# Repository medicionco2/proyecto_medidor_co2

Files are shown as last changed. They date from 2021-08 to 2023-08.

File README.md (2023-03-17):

# Medidor CO2 para prevención de contagios por aerosoles en ambientes interiores

> Este proyecto está en plena evolución. Este texto, los programas, y demás materiales se están actualizando frecuentemente.

Al respirar, absorbemos oxígeno del aire y al exhalar expulsamos dióxido de carbono (CO2). En ambientes interiores, con el correr de los minutos, si no se ventila, la respiración de las personas allí presentes hace que suba la concentración de CO2. Dicho en números, al aire libre la concentración de CO2 es de 400 ppm (partes por millón), mientras que en la exhalación de las personas, hay 40 mil ppm. Se ha demostrado que hay correlación entre esa concentración y el riesgo de contagio de enfermedades respiratorias. Por supuesto, ese riesgo varía según la proporción de personas infectadas en la región. Se estima que si la concentración de CO2 alcanza las 800 ppm, eso quiere decir que el 1% del aire que respiramos ya fue respirado por otra persona. Cuando se supera ese valor, la permanencia en ese espacio comienza a ser riesgosa. Recordemos que hay una antigua prescripción médica sobre ventilar para prevenir el contagio de enfermedades respiratorias. Durante la pandemia de COVID-19, esa recomendación se transformó en la principal para minimizar el riesgo de contagio. En resumen, es importante medir la concentración de CO2 para saber si un ambiente interior está suficientemente ventilado dada una cierta cantidad de gente y el tiempo transcurrido realizando una actividad. 

Contagio por aerosoles

> Tiene que quedar claro que si en un ambiente se mide más de 2000 ppm de CO2, hay que tomar medidas urgentemente porque realizar actividades allí es peligroso.

Se propone el diseño de un dispositivo medidor de CO2, de uso orientativo, para espacios interiores, como medida de prevención de enfermedades infecciosas que se contagian mediante aerosoles (por ejemplo, COVID-19). 

El objetivo es que el dispositivo propuesto sea de uso sencillo, lo más económico posible, de diseño libre, y con el potencial para desarrollar toda la funcionalidad de los dispositivos comerciales más avanzados. El dispositivo solamente tiene cuatro componentes. Además del sensor y la computadora, hay un LED RGB para indicar, mediante colores, el nivel de concentración de CO2 en el ambiente interior donde se use. El cuarto componente, es simplemente un pulsador. 

El diseño cuenta con una computadora de placa reducida, también llamado de placa única, de placa simple (SBC), o sistema en un chip (SoC), de bajo costo. En este caso, el sistema propuesto es de la familia ESP32 con tecnología Bluetooth y WiFi integrada. Por eso último, el instrumento no va a necesitar una pantalla, en su lugar, una app para Android o una aplicación web, van a mostrar los valores de CO2 actuales, las series de tiempo, y otros análisis para estudio y toma de decisiones (por ejemplo, ventilar más, reducir el aforo, etc.).

La situación sanitaria evidencia la necesidad de usar este tipo de dispositivos, no solo en esta coyuntura, sino post-pandemia, como elemento que apunta a asegurar un nivel de calidad de aire desde el punto de vista sanitario. En otras palabras, sería un elemento más de seguridad e higiene en espacios donde se realicen diferentes tipos de actividades humanas, incluida la educación en todos sus niveles.

### ¿Qué son los aerosoles?

Cuando hablamos, gritamos, cantamos, tosemos, estornudamos o simplemente respiramos, exhalamos partículas grandes y también partículas pequeñas ("aerosoles") que están formadas por saliva o líquido proveniente de la tráquea, los pulmones, etc. Lo mismo que las partículas grandes, estos aerosoles pueden "portar" virus, que pueden infectar cuando se inhalan.

Aerosoles

## Lista de materiales

Cualquier persona o grupo con entusiasmo, con un poco de conocimiento de electrónica e informática, y muy pocas herramientas puede construír este medidor. 

Se necesitan cuatro componentes más los cables de conexión y el gabinete.
1. ESP32: Hay diversos modelos y versiones del SoC ESP32.
2. Sensor MH-Z19b (o c, que es más actual): asegurarse que es original (Winsen)

Sensor MH-Z19b

Sensor MH-Z19c

3. Pulsador
4. LED RGB más 3 resistencias 220 ohm. Por simplicidad, se recomienda que sea en un solo módulo, como en la siguiente figura:

Modulo LED RGB

En esta aplicación, el significado de los colores es el siguiente:
- Verde significa baja concentración de CO2, bajo riesgo de contagio por aerosoles.
- Amarillo es acercándose a riesgo alto.
- Rojo es riesgo alto, debe ventilarse el ambiente.
- Violeta es riesgo alto, debería evacuarse momentáneamente el ambiente.

El LED en azul significa que el sensor se está calentando o que el aparato está en modo de calibración.

Desarrollamos una caja a medida imprimible en 3D. Se agradece a [Franco Perez](https://github.com/FrancoGabrielPerez) por su colaboración en el desarrollo del diseño 3D de la caja. También se agrade por su colaboración inicial a [Tomas Aranda](https://github.com/jarandat).

https://user-images.githubusercontent.com/53094209/226057489-6c33f7e1-ac5b-46c4-9dbb-f1a19d471beb.mp4

Mientras tanto, o alternativamente, a caja puede ser una caja de paso de las que se usan en electricidad, de las más pequeñas. Es importante que hagas dos ranuras por donde el sensor vea el exterior de la caja. Las ranuras son para las dos "ventanitas" blancas que se ven en la figura del sensor.

### Sobre el sensor

El sensor seleccionado, MH-Z19b, se basa en tecnología de detección de gas por absorción de luz infrarroja. Más precisamente, la tecnología que usa se conoce como NDIR (del inglés nondispersive infrared).

No todos los sensores MH-Z19b que se pueden adquirir son iguales, su diseño y su firmware han ido evolucionando. La librería que usamos permite acceder al "Firmware Version", por ejemplo los que tenemos son versión 5.02. Hay que notar que el fabricante (Winsen, China) no ha documentado todos los cambios y algunas veces hay que recurrir a ingeniería inversa para descubrir algunas de sus características. Aún así, se considera que es un sensor económico con una relación precio/prestaciones muy buena.

Advertencia: El sensor es sensible a la electricidad estática. Tratar al sensor con ciudado, es un componente delicado.

## Conexión de componentes

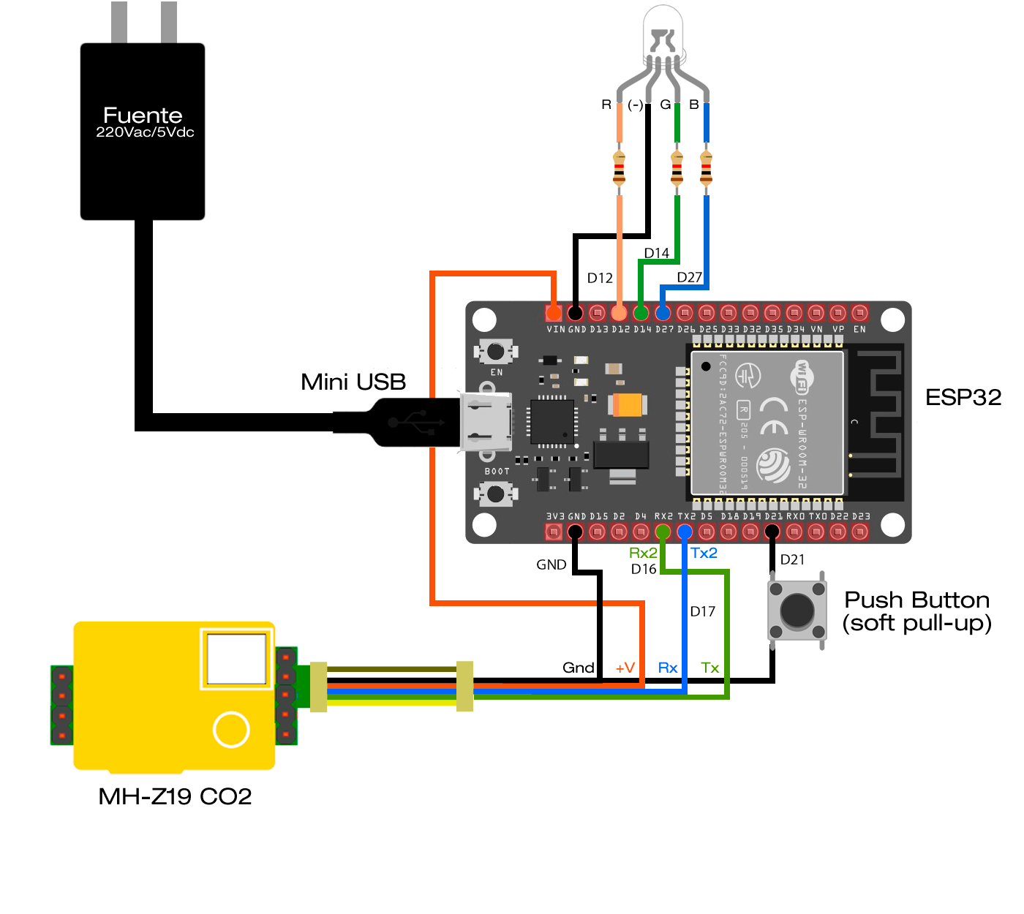
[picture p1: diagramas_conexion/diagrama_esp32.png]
Diagrama de conexiones


La alimentación del dispositivo se hace mediante un cargador USB estándar.

El sensor puede venir con un cable armado con una ficha que no es compatible con los conectores del ESP32. Por eso, una alternativa es cortar el cable y empalmar cables dupont.

Para más ayuda, [este video](https://www.youtube.com/watch?v=vmDCqNXVZKQ) muestra en detalle cómo se conecta el sensor MH-Z19b al ESP32. 

En resumen, conectar el sensor requiere de 4 cables: 
- Alimentación (5V): cable rojo del sensor 
- tierra (GND): cable negro
- y los dos cables de la conexión serie: cable azul a pin Tx2 (o puede aparecer impreso con número 17) y cable verde a Rx2 (o 16). 

## Programación

1. Instalar IDE Arduino en una PC. 
2. Instalar soporte para ESP32.
Las instrucciones para estos dos primeros pasos se pueden ver en [este enlace](https://randomnerdtutorials.com/installing-the-esp32-board-in-arduino-ide-windows-instructions/) 
	
3. Instalar librería para el sensor MH-Z19b.
	https://downloads.arduino.cc/libraries/github.com/WifWaf/MH_Z19-1.5.3.zip
	
   También se puede usar el gestor de librerías. Para ello, se puede ir, en el Arduino IDE, al menu “Herramientas”, allí “Administrar Librerías…”. Aparece una ventana donde se puede buscar “MH-Z19”, que es nuestro sensor, y vamos a instalar la librería seleccionada en la figura, es decir, la de “Jonathan Dempsey”.
   
4. Copiar y compilar el código fuente seleccionado usando Arduino IDE.

5. Descargar el código ejecutable en el ESP32 de manera que quede programado con la aplicación seleccionada.

## Funcionamiento

Una vez conectado el cable USB, el dispositivo se pone en funcionamiento. No hay botón de encendido. El sensor tarda tres minutos para iniciar sus medidas, eso se indica con el LED encendido en color azul. Pasado ese tiempo, el LED indica la concentración de CO2 mediante colores: verde (poca concentracón de CO2, más seguro), amarillo, rojo y violeta (muy alta concentración de CO2, menos seguro). A su vez, se envían las medidas de CO2 y temperatura por WiFi o Bluetooth, según cuál programa se haya cargado en el dispositivo. 

Si se seleccionó la versión Bluetooth, se pueden ver las medidas en un teléfono inteligente. Una posibilidad es usar la app "Serial Bluetooth Terminal" que se pude descargar en el teléfono desde https://play.google.com. En ese caso vas a ver los datos que vienen del medidor de esta manera:

Captura Serial Bluetooth Terminal

### Cómo debería usarse el medidor

En un espacio interior con cierta ventilación fija, por ejemplo con las ventanas parcialmente abiertas, se debería llegar a una situación en la cual el CO2 que exhalan las personas sea igual a la cantidad de CO2 que sale por las ventanas, de modo que el nivel de CO2 en la habitación se mantenga aproximadamente constante. El objetivo debe ser que ese valor estable de CO2 no supere los 700 a 800 ppm.

Si se observan valores estables de CO2 demasiado altos, superiores a 800 ppm, se deben abrir las ventanas un poco más. Si eso no es posible porque la temperatura del exterior es demasiado baja, se debe reducir el número de personas que realiza la actividad o reducir la duración de la actividad. Si la temperatura exterior fuera confortable, se recomienda abrir las ventanas completamente.

El viento hace que mejore la ventilación. En días ventosos, es probable que se logren los valores deseados de CO2 con menor apertura de las ventanas.

> Ventilar los pasillos en las escuelas (y otros edificios con varios espacios comunicados) es muy importante, ya que de lo contrario transfieren el aire exhalado entre las aulas.

imagen

### En qué lugar del espacio interior colocar el medidor

Lo ideal es colocarlo a la altura de la respiración de las personas (1,5 m) del lado opuesto a las ventanas. No colocarlo muy cerca de las personas.

Se puede experimentar moviendo el medidor de CO2 a diferentes lugares de la habitación. Si se detecta una zona menos ventilada, allí debe colocarse el medidor para que indique el caso más desfaborable.

### Calibración

Al aire libre, la concentración de CO2 es cercana a las 400 ppm. Si ves que en un ambiente muy bien ventilado, el medidor está dando una medida alejada de esas 400 ppm, seguramente haga falta calibrarlo.

Si bien existen diferentes [técnicas de calibración](https://www.co2meter.com/blogs/news/7512282-co2-sensor-calibration-what-you-need-to-know), en este caso vamos a poner el dispositivo al aire libre. Hay que notar que el proceso se ve afectado por el viento y las temperaturas extremas. Alternativamente, el medidor se puede calibrar en un espacio MUY bien ventilado. Para comenzar el proceso de calibración, oprimir el pulsador por al menos un segundo y esperar al menos 20 minutos. En ese estado, el LED está encendido en color azul con intensidades variables que se repiten cíclicamente. 

Alternativamente, existe un modo de calibración que se llama [Automatic Background Calibration](https://www.co2meter.com/blogs/news/9290675-automatic-background-calibration-abc-in-senseair-co2-sensors-explained) (ABC). En este modo el sensor mide durante 24 horas, se queda con el mínimo y usa ese mínimo para ajustar de manera que ese valor mínimo pase a ser 400 ppm. Si el ambiente interior se usa de manera que durante una parte del día se ventile lo suficiente, esta estrategia funcionaría de manera automática, sin intervención de usuarios.

## Propuesta

Con motivaciones parecidas, en Internet existen varios proyectos como éste. En este caso, el concepto que nos guía es el de *IoT, Internet de las Cosas*, donde el hardware es mínimo, con conexión a Internet, y donde el valor está en el software, hasta llegar a usar una plataforma IoT. Esas plataformas (existen más de 600 diferentes) proveen servicios como seguridad, actualización remota del software, visualización de los datos, gestión de eventos, gestión de los propios dispositivos en el caso que se usen varios, o muchos, y por qué no miles.

Otra diferencia es que este proyecto se centra en *un solo tipo de sensor y un solo tipo de "computadora de placa simple"*. Existen varias alternativas para ambos, pero para quien comienza, creemos que es más sencillo tener una sola plataforma. Como decíamos, el concepto que nos guía es que el valor va a estar en el software. En cuanto al software, sí proponemos diferentes versiones para Wifi, Bluetooth, con funcionalidad básica, y esperemos que pronto, funcionalidad más avanzada.

> Y lo más importante de todo: Generar conciencia sobre la seguridad e higiene del aire que respiramos en ambientes interiores. Higiene

Te invitamos a sumarte a este proyecto, a construír tu propio medidor, compartir resultados, y a extender el hardware pero sobre todo, el software. Para consultas, por favor, escribir a etodorov@exa.unicen.edu.ar.

## ¿Estos medidores compiten con los medidores comerciales?

En este proyecto, de ninguna manera competimos con los medidores comerciales. De hecho, te invitamos a visitar [páginas de fabricantes de medidores en Argentina](https://www.argentina.gob.ar/ciencia/unidad-coronavirus/ventilar/produccion-local-medidores) para más información. Los medidores de este proyecto pueden complementar, llegando a los sectores de menos recursos donde las soluciones comenciales son inaccesibles, ayudando al objetivo fundamental de la prevención y la toma de consciencia sobre la vía de contagio por aerosoles. 

## Más Información

- La concentración de CO2, además de poder medirse, se puede calcular en base al tamaño de la habitación, la cantidad de personas presentes y la ventilación. Esta última se mide en "cambios de aire por hora". https://forhealth.org/tools/co2-calculator/

- Este artículo del diario "El País", de octubre de 2020, es insuperable desde el punto de vista comunicacional. https://elpais.com/ciencia/2020-10-24/un-salon-un-bar-y-una-clase-asi-contagia-el-coronavirus-en-el-aire.html

- [Importancia de la ventilación para la prevención de la COVID-19](https://youtu.be/fpMb1TzraGw).  Canal del Ministerio de Ciencia, Tecnología e Innovación, 26 marzo de 2021.   

- [Recomendaciones para la prevención de transmisión de COVID-19 por aerosoles](https://www.argentina.gob.ar/sites/default/files/covid-19-prevencion-de-transmision-por-aerosoles-2021.pdf) del Ministerio de Ciencia, Tecnología e Innovación y Ministerio de Salud.

- Campaña [Ventilar](https://www.argentina.gob.ar/ciencia/unidad-coronavirus/ventilar) para la prevención de la transmisión del COVID-19 por aerosoles, del Ministerio de Ciencia, Tecnología e Innovación, Argentina.

- [Guía de evaluación de la frecuencia de ventilación](https://schools.forhealth.org/ventilation-guide/). Programa "Healthy Buildings" de la Escuela de Salud Pública T.H. Chan, Universidad de Harvard. 

- [Guía del Consejo Superior de Investigaciones Científicas](https://www.csic.es/en/node/1259002) (España) sobre cómo se deben ventilar para reducir el riesgo de contagio por Covid-19. 

- [Estimación de riesgo de contagio simplificada](https://www.nationalgeographic.com/science/article/how-to-measure-risk-airborne-coronavirus-your-office-classroom-bus-ride-cvd) de National Geographic.

- Natalia Rubinstein, Ciclo Ciencia para ventilar: [Yo ventilo, ella ventila, vos ventilás. ¿Pero lo hacemos bien?](https://youtu.be/4q3odycwvYs).

- Sandra Cordo, Ciclo Ciencia para ventilar: [Transmisión de Covid-19 por aire. Principales medidas de prevención](https://youtu.be/4AUWS4Dpn0A).

- Alejandro Nadra, Juan Fernández Zaragoza, Ciclo Ciencia para ventilar: [¿Qué son las tecnologías libres y qué aportan en el contexto de pandemia?](https://youtu.be/301sSYFhCg8).

---

- [Jornada sobre Ventilación para bares y restaurantes](https://youtu.be/Q7DBwQ0G1Hc) en contexto de COVID 19, donde se presentaron [líneas de financiamiento](https://www.argentina.gob.ar/servicio/obtener-un-credito-para-mi-restaurante-o-bar) de la Secretaría de la Pequeña y Mediana Empresa y los Emprendedores de Argentina, hasta 31 de octubre de 2021.

---

- Proyectos afines y material técnico

	- Proyecto del [Dr. Jorge Aliaga]((http://www.jorgealiaga.com.ar/?page_id=2864)) de [Medición de CO2](https://github.com/jlaliaga/Medidor-de-CO2)  

	- Proyecto [Aireamos](https://www.aireamos.org), como coalición de grupos liderados por científicos en el área.

		- [Comparativas y guías](https://www.aireamos.org/medidores/) sobre medidores comerciales de CO2.
      
	- [Proyecto LibreCO2](https://github.com/danielbernalb/LibreCO2) de [Daniel Bernal](https://aireciudadano.com/guia-de-construccion-medidor-libreco2/) donde se propone el uso de tarjetas Arduino.
      
	- Un [medidor de CO2](https://emariete.com/medidor-casero-co2/) de eMariete.

		- [Ciudado con los sensores *fake*](https://youtu.be/dWYMuFZt8kk).

	- [Proyecto CODOS](https://github.com/miguelangelcasanova/codos).

	- [Comparativa de sensores](https://soloelectronicos.com/2020/11/01/monitor-de-co2-con-sensor-mh-z19/): Recomiendan el MH-Z19, lo mismo que Jorge Aliaga. Aunque la medida de temperatura que provee el propio sensor no es precisa, al tener esa medida junto con CO2, se puede controlar la habitabilidad de un espacio con un criterio CO2 y temperatura combinado.

	- ¿Cómo funcionan los sensores de tecnología NDIR? Explicación sencilla en [co2meter.com](https://www.co2meter.com/blogs/news/6010192-how-does-an-ndir-co2-sensor-work)
      
 - Artículos científicos

	- Zhe Peng and Jose L. Jimenez, "Exhaled CO2 as a COVID-19 Infection Risk Proxy for Different Indoor Environments and Activities", Environmental Science & Technology Letters, 2021, 8 (5), 392-397. https://pubs.acs.org/doi/10.1021/acs.estlett.1c00183

	- Greenhalgh T, Jimenez JL, Prather KA, Tufekci Z, Fisman D, Schooley R. "Ten scientific reasons in support of airborne transmission of SARS-CoV-2". Lancet. 2021; 397: 1603-1605. https://www.thelancet.com/journals/lancet/article/PIIS0140-6736(21)00869-2/fulltext

	- Liu, Y, Misztal, PK, Xiong, J, et al., "Detailed investigation of ventilation rates and airflow patterns in a northern California residence", Indoor Air, 2018; 28: 572–584. https://onlinelibrary.wiley.com/doi/10.1111/ina.12462

	- Johansson MA, Quandelacy TM, Kada S, et al. "SARS-CoV-2 transmission from people without COVID-19 symptoms". JAMA Netw Open 2021; 4: e2035057.

	- Lidia Morawska, Donald K Milton, "It Is Time to Address Airborne Transmission of Coronavirus Disease 2019 (COVID-19)", Clinical Infectious Diseases, Volume 71, Issue 9, 1 November 2020, Pages 2311–2313. https://academic.oup.com/cid/article/71/9/2311/5867798
		- Este paper fue suscrito por más de 200 científicos.

	- Hou YJ, et al. SARS-CoV-2 Reverse Genetics Reveals a Variable Infection Gradient in the Respiratory Tract. Cell. 2020 Jul 23;182(2):429-446. https://www.ncbi.nlm.nih.gov/pmc/articles/PMC7250779/pdf/main.pdf

	- Miller, SL, Nazaroff, WW, Jimenez, JL, et al. Transmission of SARS-CoV-2 by inhalation of respiratory aerosol in the Skagit Valley Chorale superspreading event. Indoor Air. 2021; 31: 314– 323. https://onlinelibrary.wiley.com/doi/epdf/10.1111/ina.12751

	- Shrey Trivedi, Savvas Gkantonas, Léo C. C. Mesquita, Salvatore Iavarone, Pedro M. de Oliveira, and Epaminondas Mastorakos, "Estimates of the stochasticity of droplet dispersion by a cough", Physics of Fluids 33, 115130 (2021) https://doi.org/10.1063/5.0070528 
		- Este paper fue citado en un [artículo periodístico](https://www.pagina12.com.ar/385125-coronavirus-advierten-que-con-el-distanciamiento-social-no-a) donde los investigadores concluyeron que el distanciamiento de dos metros no debe considerarse una medida de seguridad por sí sola, sino que para ser efectiva tiene que estar acompañada por la utilización de barbijos, la ventilación de espacios y la vacunación. “Todos estamos desesperados por ver la parte posterior de esta pandemia, pero recomendamos encarecidamente que las personas sigan usando máscaras", al menos en "espacios interiores", dijo Epaminondas Mastorakos, experto en mecánica de fluidos de la Universidad de Cambridge. "No hay ninguna buena razón para exponerse a este riesgo mientras el virus esté con nosotros”, añadió.

- El proyecto en los medios

	- En el canal de YouTube de El Taller De TD imagen [explicaron el proyecto](https://youtu.be/7OHqT15nE9wimagen
), 11 OCT 2021. ¡Gracias!

	- Exactas Dialoga, 5 OCT 2021. [Medidor sencillo de dióxido de carbono.](https://www.mixcloud.com/Exactasdialoga/exactas-dialoga-e5-medidor-sencillo-de-di%C3%B3xido-de-carbono/)

	- Diario "ABC Hoy" de Tandil, 30 SEP 2021. [Alumnos de 5° Año del Colegio Nuestra Tierra diseñaron un detector de Dióxido de Carbono.](http://www.abchoy.com.ar/leernota.php?id=178465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)

	- Diario "La Voz de Tandil", 29 SEP 2021. [Estudiantes del Colegio Nuestra Tierra construyeron un medidor de dióxido de carbono.](https://www.lavozdetandil.com.ar/2021/09/29/estudiantes-del-colegio-nuestra-tierra-construyeron-un-medidor-de-dioxido-de-carbono)

	- Portal "Enfoque de Negocios", 16 JUL 2021. [Se fabricarán medidores de Dióxido de Carbono en Tandil.](https://www.enfoquedenegocios.com.ar/medidores-de-dioxido-de-carbono/)

	- [Presentación del proyecto](https://youtu.be/HmPg_Kn5Qhk) en el Encuentro IoT MdP/Tandil 2021 en el marco del proyecto [NEON](https://www.project-neon.eu/) de la Unión Europea, 13 JUL 2021. 

	- Diario "El Eco" de Tandil, 3 JUL 2021. [Investigadores de Exactas inventaron un medidor de dióxido de carbono con un diseño económico y simple.](https://www.eleco.com.ar/la-ciudad/investigadores-de-exactas-inventaron-un-medidor-de-dioxido-de-carbono-con-un-diseno-economico-y-simple)

	- Boletín de la Facultad de Ciencias Exactas - Número 274 - Reunión con la Dirección Nacional de Desarrollo Tecnológico e Innovación del MinCYT, 28 JUN 2021. (En redes sociales de la Facultad de Ciencias Exactas, UNICEN)

	- Diario "ABC Hoy" de Tandil, 23 JUN 2021. [Medidor de dióxido de carbono para concientizar sobre ventilación para prevención del COVID-19.](http://www.abchoy.com.ar/leernota.php?id=175998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)

	- Diario "El Eco" de Tandil, 23 JUN 2021. https://www.eleco.com.ar/la-ciudad/crean-un-medidor-de-dioxido-de-carbono-que-busca-concientizar-la-importancia-de-la-ventilacion-de-los-ambientes

	- Boletín de la Facultad de Ciencias Exactas - Número 273 - Crean un medidor de Dióxido de Carbono que busca concientizar la importancia de la ventilación de los ambientes para evitar la propagación del COVID-19, 22 JUN 2021. (En redes sociales de la Facultad de Ciencias Exactas, UNICEN)

¿Se puede usar esta información en otras publicaciones?

Si, se puede utilizar. De hecho, nosotros consultamos numerosas fuentes que tratamos de documentar en esta sección. No es necesario que te pongas en contacto con nosotros para pedirnos permiso. Sólo te pedimos que indiques el enlace a esta página como fuente de la información. Si es posible, incluir la fecha en la que viste la información. Si necesitas una lista de autores, sólo tienes que enumerar a las personas que contribuyen en este proyecto en la fecha que accediste.

Con respecto al código fuente, recuerda que tiene licencia GPL, lo cual permite usar, estudiar, compartir (copiar) y modificar el software, siempre que preserves estas libertades.

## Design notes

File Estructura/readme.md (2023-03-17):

La estructura esta diseñada en Fusion360, se incluye un .f3z que contiene el ensamblaje completo de la estructura. Ademas se incluyen tres archivos .stl correspondientes a las diferentes partes del diseño.
Esta diseñado para ser impreso sin soportes.

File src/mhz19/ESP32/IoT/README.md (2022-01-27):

## thingspeak

Thingspeak (https://thingspeak.com) es un proyecto open source (https://github.com/iobridge/thingspeak) creado en 2010. Actualmente, está integrado con el software MATLAB de MathWorks al punto que hay que crear una cuenta en MathWorks para usar la plataforma en thingspeak.com. 

Para usar esta alternativa hay que: 

1. Comenzar siguiendo los pasos que se explican en https://la.mathworks.com/help/thingspeak/collect-data-in-a-new-channel.html.

2. Crear un channel y configurarlo para recibir dos "Fields", uno va a contener la lectura de CO2 y otro la temperatura del sensor.

Channel Settings

3. Si ya seguiste los [pasos](https://github.com/medicionco2/proyecto_medidor_co2#programaci%C3%B3n) de las versiones básicas, ya tenías cargada la librería del sensor. Ahora, tenés que cargar la librería thinkspeak que está disponible en el repositorio de Arduino.

Lib thikgspeak

4. Editar el archivo secrets.h, que debe incluirse en el IDE de Arduino, indicando tu "Channel Id" y tu "Write API Key" en thingspeak. Los API Key son 16 números y letras, tachados por seguridad en la figura.

API Key

5. Configurar el ESP32 con ese programa. 

El medidor en funcionamiento va a comenzar a enviar datos a la plataforma thingspeak. Vas a poder configurar visualizaciones de manera más o menos intuitiva de manera que veas algo así:

thingspeak Visualization

Licencia seleccionada: FREE (For small non-commercial projects)

  - Scalable for larger projects:   No. Annual usage is capped.
  - Number of messages:             3 million/year (~8200/day)
  - Message update interval limit:  Every 15 seconds 
  - Number of channels:             4
  - MATLAB Compute Timeout:         20 seconds
  - Number of simultaneous MQTT subscriptions: Limited to 3
  - Private channel sharing:        Limited to 3 shares
  - Technical Support:            	Community Support 

Para tener más nivel de servicio (conectar más sensores, compartir con más gente, mejores tasas de datos, etc.), hay que adquirir alguna licencia de pago: Standard, Academic, Student, o Home.

### ¿Cómo crear un dashboard sencillo para ver la telemetría de todos los sensores en una página web?

A continuación te explicamos cómo hacerlo.

#### Embebiendo Código de Cuadros de Medición y Visualización de Thingspeak

Si queremos agregar un cuadro de visualización de una medición dentro de una página web, debemos embeber una porción de código html. Para realizarlo, dentro de thingspeak.com con nuestra cuenta y nuestro canal que queremos mostrar, debemos seleccionar el cuadro del campo ("Field") que queremos mostrar y debemos seleccionar el icono que se muestra a continuación: 

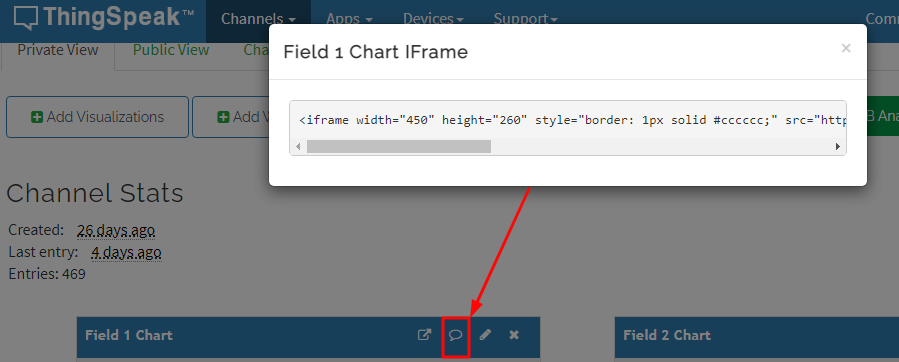
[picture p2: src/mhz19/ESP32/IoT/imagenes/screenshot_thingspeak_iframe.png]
thingspeak Código Cuadros de Medición y Visualización embebido


Una vez seleccionado el icono tendremos acceso a copiar el código a embeber, se trata de una etiqueta iframe que puede agregarse en cualquier sitio web. Si aún no tenemos un sitio web, podemos pegar ese código en un archivo y pasar al paso de crear un sitio web.

#### Creando un sitio web en Google Sites

Si disponemos de una cuenta de gmail, podemos desarrollar un sitio web que estará alojado en Google, accesible por cualquier persona.
Una vez iniciada nuestra cuenta de gmail, se puede acceder a https://sites.google.com/ para comenzar a costruir un sitio web.

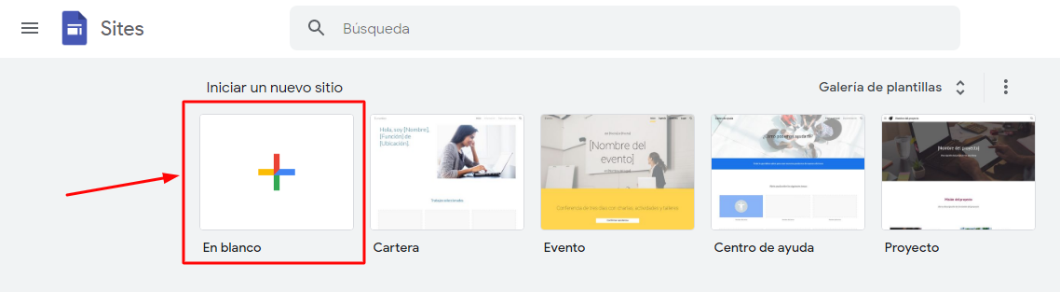
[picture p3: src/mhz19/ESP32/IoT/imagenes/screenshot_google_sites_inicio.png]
Inicio Google Sites


Una vez que se ingresa al inicio de la construcción de nuestro sitio en Google, se puede agregar un título a nuestra página, bloques de estructra, estilos, etc. Aquí lo importante es que para mostrar nuestras mediciones debemos agregar un bloque que permita pegar nuestro código de thingspeak. Ese bloque que permite introducir códgo html, se puede agregar como indica la figura, cliqueando en "Incorporar <>" y luego dentro del cuador de diálogo seleccionando "Incorporar código" nos permite en el casillero de texto pegar nuestro código generado desde thingspeak para nuestro cuadro de medición y visualización.

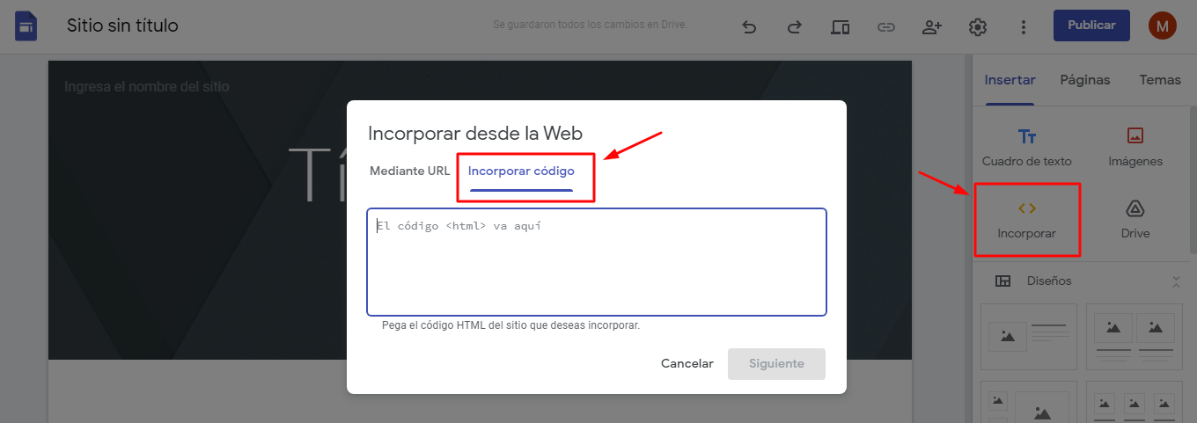
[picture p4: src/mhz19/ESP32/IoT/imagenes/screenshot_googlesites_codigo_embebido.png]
Embebiendo Cuadros de Medición y Visualización de Thingspeak en Google Sites


Luego para finalizar podemos hacer más ajustes de alineación y estilo de nuestra página y publicarla. Si en esa misma página queremos mostrar otro gráfico,y esa es la idea de un dashboard, o cuadro de control, repetimos los pasos anteriores.

## Autodescubrimiento de la red WiFi

En versiones simples del firmware, por ejemplo para hacer un solo medidor, el nombre de la red WiFi (conocido como SSID) y la contraseña, se proporcionan en el programa, en nuestro caso, en el archivo secrets.h. Si se cambia el router, o se lleva el medidor a otra red, hay que volver a editar el archivo secrets.h y reprogramar el medidor. Si bien esa forma de conectarse a la red WiFi es sencilla, por un lado es incómodo para los usuarios tener que reprogramar los medidores, y por otro lado complica el despliegue en instituciones que necesiten de un número relativamente grande de medidores. Una solución es agregar una funcionalidad que se llama autodescubrimiento de la red WiFi (o WiFi provisioning).

Esta técnica va a permitir distribuír medidores ya programados, que no deberán reprogramarse, de manera que sean más sencillos de usar para los usuarios finales. Sin embargo, para quienes quieran estudiar el programa, se van a encontrar con un código más complejo que en el caso simple de arriba.

WiFi provisioning es un proceso que va a servir para cargar en el medidor- sin tener que programar- el SSID, password, e información para enviar los datos a la plataforma IoT, en este caso Thingspeak. Esta funcionalidad puede ser muy útil en dispositivos IoT como nuestro medidor. El medidor va a poder estar en uno de dos modos: con la configuración cargada o sin la configuración cargada. Si la configuración no está cargada, el medidor se va a comportar como un Access Point y lo vamos a ver entre las redes WiFi disponibles, caso contrario el medidor se conecta a la red que tiene configurada y opera normalmente midiendo y enviando datos a la plataforma IoT.

Para usar el medidor con esta funcionalidad hay que hacer los tres primeros pasos (1-3) de las instrucciones de aquí arriba, luego:

4. Configurar el ESP32 con el programa correspondiente (Thingspeak_WiFi_provisioning.ino). Se le puede entregar el medidor a un usuario final con estos 4 pasos hechos, así él o ella, solamente va a tener que realizar el quinto paso sin tener que lidiar con tecnología. 

5. El medidor en funcionamiento va a enviar datos a la plataforma thingspeak como antes. Pero para que ello ocurra, primero lo vas a tener que configurar del siguiente modo:

  - Durante el primer arranque del dispositivo, el medidor se configura como un punto de acceso (AP - Access Point) y crea una red abierta Wifi sin contraseña con el nombre "redmedidor". Entonces, para establecer la conexion con el punto de acceso, en el dispostivo desde el que se desee conectar al medidor (teléfono, PC, etc.) se debe seleccionar esa red con el nombre "redmedidor". 

Conexión al medidor como Access Point

  - Esta red abierta WiFI permite al usuario conectarse al medidor a través de un navegador. Para ello, debe ingresarse la dirección http://192.168.4.1 en el navegador para acceder a la página web de configuración.

Configurando el medidor

  - Para dar una cierta seguridad, hay que ingresar usuario y contraseña para poder acceder al medidor. Si no los cambias en el programa, son: "esp32", "4321".

Ingreso a la configuración del medidor

  - Una vez seleccionado el nombre de red, contraseña, y demás información, el medidor se reinicia e intenta conectarse a la red asignada.

  - Si se establece la conexion el proceso de provisioning se ejecutó exitosamente.

  - En caso de falla o si se quiere modificar la red a la cual se conecta el medidor, se debe pulsar el botón por más de tres segundos para que el dispositivo pase nuevamente al modo de punto de acceso. 

## Actualización OTA del firmware

Tener un dispositivo como este medidor de CO2 progeamado y funcionando, no significa que esté libre de errores de programación o que nunca vaya a nececitar mejoras. Al contrario, mientras el proyecto esté activo, periódicamente se va a necesitar actualizar el código del ESP32, el firmware. Esto se puede hacer de diferentes maneras, la más sencilla es compilar el nuevo código y programar el ESP32 mediante el cable USB desde la PC. Es lo que se hace cuando se trabaja con prototipos, para hacer pruebas en casa, pero para un usuario esto puede ser demasiado tecnológico, no muy amigable. Más allá de eso, si tenemos una cantidad de medidores desplegados en un edificio, actualizar el firmware de esa manera también es impráctico. Aquí viene entonces la segunda manera: aprovechar la conectividad WiFi para actualizar el firmware remotamente, "over the air" (OTA). En este caso, quien administre los sensores y la plataforma IoT, va a subir la actualización a un servidor, posteriormente el ESP32 va a descargarla en su memoria y va a reiniciarse automáticamente. A partir de ese momento todos los medidores de ese edificio van a estar actualizados sin intervención de los usuarios. Es un mecanismo muy usado, de hecho es lo que hacen permanentemente los smartphones para mantenerse actualizados. 

Esta funcionalidad se agrega a la de provisioning solamente, que es la versión pensada para usos institucionales.

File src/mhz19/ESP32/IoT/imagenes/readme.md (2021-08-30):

Imagenes de Guía para embeber código de dashboards de thingspeak para una página web. Ejemplo de código embebido para un Sitio de Google.

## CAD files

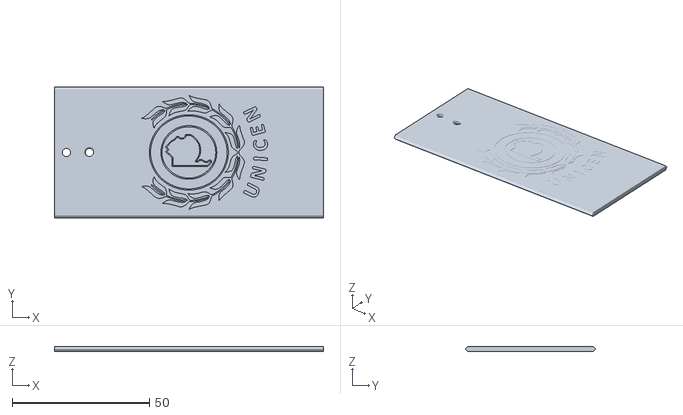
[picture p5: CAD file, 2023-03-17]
Estructura/Tapa.stl
98.0 x 47.6 x 1.86

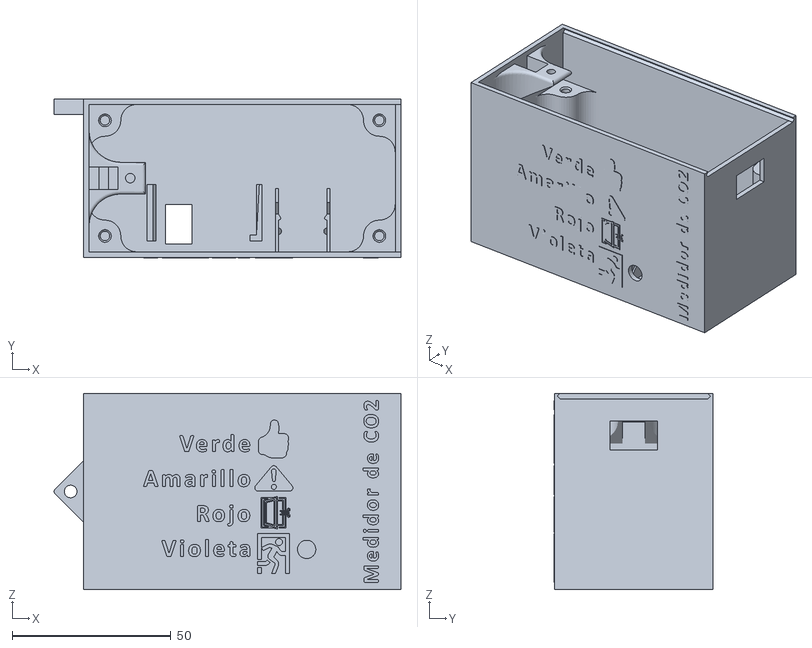
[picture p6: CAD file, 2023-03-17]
Estructura/Caja.stl
109.2 x 50.2 x 61.9

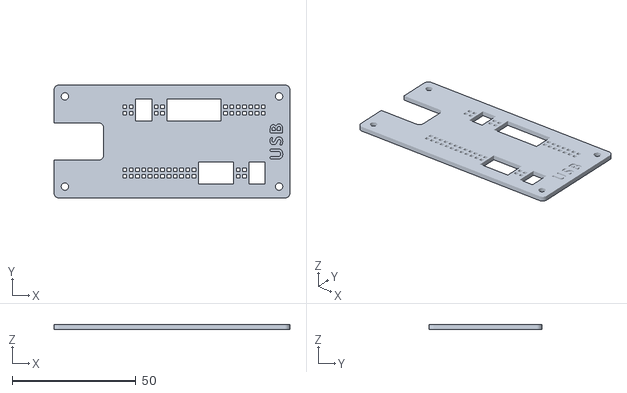
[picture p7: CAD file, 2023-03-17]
Estructura/Placa.stl
95.2 x 45.6 x 2.00

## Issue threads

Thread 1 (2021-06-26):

Sensor devuelve -1 después de setup

etodorovich, 2021-06-26:
A veces el sensor MH-Z19 retorna error (-1), cuando se pide CO2 o temperatura, después de setup (). Estudiando la librería, puede ser que esté fallando el checksum al hacer la lectura del sensor por el puerto serie.

Ver: MHZ19_uart.cpp, a partir de línea 111:
`int MHZ19_uart::getSerialData(MHZ19_DATA flg) {`
...

Por ahora, para solucionarlo se debe desenchufar y enchufar la alimentación.

To do:
- [ ] Tratar de recomponer el dispositivo mediante software.
- [ ] Hacer debug del sensor (HW) para determinar la causa del error de lectura.

etodorovich, 2021-06-28:
Se está usando la librería https://github.com/piot-jp-Team/mhz19_uart/pulse. Ese software se escribió hace 4 años, mientras que el firmware del sensor ha ido evolucionando.

- [ ] Evaluar la librería https://github.com/WifWaf/MH-Z19, actualizada hace 6 meses

etodorovich, 2021-06-29:
Se está usando la librería https://github.com/piot-jp-Team/mhz19_uart/pulse. Ese software se escribió hace 4 años, mientras que el firmware del sensor ha ido evolucionando.

- [ ] Evaluar la librería https://github.com/WifWaf/MH-Z19, actualizada hace 6 meses

etodorovich, 2021-06-29:
Vamos a continuar con la librería WifWaf/MH-Z19

Closed 2021-06-29.

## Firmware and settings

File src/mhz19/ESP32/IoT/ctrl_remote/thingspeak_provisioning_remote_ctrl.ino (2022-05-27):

/*
  Thingspeak_params_provisioning.ino - Program for ESP32 and MH-Z19b 
     CO2 sensor. Connects to the IoT thingspeak platform.  
     This program uses the libraries from
       https://github.com/WifWaf/MH-Z19
       https://github.com/mathworks/thingspeak-arduino
     Both available in Arduino too.
       
     Warning level signal RGB LED
     Push Button for configuation control
       (1) If the button is held down for less than 
           one second, it sets the CO2 baseline, 
       (2) if the duration is longer than one second, 
           the device goes to calibration mode.
       (3) if the duration is longer than three seconds, 
           the device goes to Access Point mode for parameters provisioning.

     Params (WiFi, thinspeak) provisioning:
       (a) During the first device bootstrap, it is configured as an access 
           point (AP) and creates an open Wifi network without password with 
           the name "redmedidor". Then, to establish the connection to this 
           access point, in the device from which you want to connect to the 
           meter (phone, PC, etc.) you must select that network with the 
           name "redmedidor".
       (b) This open WiFI network allows the user to connect to the meter 
           through a browser. To do so, the address http://192.168.4.1 must 
           be entered in the browser to access the configuration web page.
       (c) After selecting the network name, password, and thingspeak 
           comunication parameters, the meter restarts and attempts to 
           connect to the assigned network. If the connection is established, 
           the provisioning process is successful.
       (d) In case of failure or if you want to change the network to which 
           the meter is connected, press the button for more than three seconds 
           to switch the device back to the access point mode.

  Copyright (c) 2021-2022 Elías Todorovich, Matías Presso

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
You should have received a copy of the GNU General Public License
along with this program.  If not, see <https://www.gnu.org/licenses/>.
*/

#include "eco2.h"

int d = 0;
const int S = 3; // Samples per telemetry recording
const int initialConnectAttempts = 5; //Number of WiFi connection attempts at Start UP


/*----------------------------------------------------------
  WiFi connection in an ESP32s
  ----------------------------------------------------------*/
#include <WiFi.h>
#include <EEPROM.h>

String ssid;       // your network SSID (name)... stored in EEPROM
String password;   // your network password... stored in EEPROM

WiFiClient myClient;

/*----------------------------------------------------------
  Access Point mode in an ESP32s
  ----------------------------------------------------------*/
//#include <HTTPClient.h>
#include <WebServer.h>

WebServer server(80);  //Local server at port 80

int statusCode;
const char* AP_ssid = "redmedidor";
const char* AP_pass = "";

//Local Device Credencials
const char* local_user_esp32 ="esp32";
const char* local_pass_esp32 ="4321";

//HTML CONTENT
String content;
String content_fixed_up;
String content_dynamic;
String content_fixed_down;
String netListHtml;

int totalNets;

bool AP_MODE = false; //Access Point State

/*----------------------------------------------------------
  ThingSpeak settings
  ----------------------------------------------------------*/
#include "ThingSpeak.h"

unsigned long myChannelNumber;
String myWriteAPIKey, myReadAPIKey;

/*----------------------------------------------------------
  Remote control settings
  ----------------------------------------------------------*/

//Calibration DATA
//Calibration Field, adjust your Thingspeak field for this purpose, remote_calibrate_state 1 (remote request), 2 (calibrate accepted by device), 0 (no calibrate, repose)
unsigned int remote_calibrate_field = 3; //Calibration Field, adjust your Thingspeak field for this purpose
int remote_calibrate_state = 0; //calibrate_state in device:  0 no calibrate, 1 calibrate request, 2 calibrate process, -1 local calibration

//Example url to update a thingspeak field and request calibration (field3=1) https://api.thingspeak.com/update?api_key=THINGSPEAK-WRITE-API-KEY&field3=1 

//Restart DATA
unsigned int remote_restart_field = 4; //Restart Field, adjust your Thingspeak field for this purpose
int remote_restart_state = 0; //remote_restart_state in device:  0 no restart, 1 restart request, 2 restart process 

//Time Set DATA
unsigned int remote_timeset_field = 5; //Time Set Field, adjust your Thingspeak field for this purpose
int remote_timeset_state = 0; //remote_timeset_state in device:  0 no timeset, 1 timeset request, 2 timeset process 


/*----------------------------------------------------------
  Getting Date and Time from NTP Server
  ----------------------------------------------------------*/
#include "time.h"
const char* ntpServer = "pool.ntp.org";
const long  gmtOffset_sec = 3600*(-3); // (GMT-3)
const int   daylightOffset_sec = 0; // offset in seconds for daylight saving time. It is generally one hour=3600

struct Mment {
  int s_co2ppm, s_temp;
  struct tm  s_timeinfo;
};

// When WiFi is not available, measurements are saved every 5 minutes. Here we can store up tu 3 hours of measurements.
const int MAX_MM = 12*3;
struct Mment mm2send[MAX_MM];
int saved2send = 0; 

void printLocalTime(){
  struct tm timeinfo;
  char buffer [25];
  
  if(!getLocalTime(&timeinfo)){
    Serial.println("Failed to obtain time");
    return;
  }
  Serial.println(&timeinfo, "%A, %B %d %Y %H:%M:%S");

  Serial.print("For thingspeak, the timestamp string must be in the ISO 8601 format: ");
  // strftime doc: https://www.cplusplus.com/reference/ctime/strftime/
  strftime (buffer,25,"%F %T-03",&timeinfo); // Example "2017-01-12 13:22:54-05"
  Serial.println(buffer);
  
  Serial.println();
}

/*----------------------------------------------------------
    Connect to WiFi in STA mode
  ----------------------------------------------------------*/
void connectWiFiModeSTA(){
  int t = 0;
  WiFi.mode(WIFI_STA);
 
  //connection init
  Serial.print("Connecting to...");
  Serial.println(ssid);
  Serial.print("with pass...");
  Serial.println(password);

  while (WiFi.status() != WL_CONNECTED){
    WiFi.begin(ssid.c_str(), password.c_str());
    Serial.print(".");
    updateRGB_LED (true);         // Blink while connecting
    delay(10000);
    if (t++>30) return; // 60s*5=300s=5min
  }

  Serial.println("");
  Serial.println("WiFi connected");
  
}

void connectWiFi_1(){
     // WiFi connection attempts (initialConnectAttempts)
     for (int i = 0; i < initialConnectAttempts; ++i) {
        WiFi.begin(ssid.c_str(), password.c_str());
        Serial.println("Connecting to Wifi...");
        updateRGB_LED (true);         // Blink while connecting
        delay(10000);

        if(WiFi.status() != WL_CONNECTED){
           Serial.println("Fail connection in attempt: " + String(i+1));
        }
        else {
           Serial.println("Connected to Wifi!");
           i = initialConnectAttempts;
        }
     }   
     
     if(WiFi.status() != WL_CONNECTED){
      Serial.println("No connection after attempts:" + String(initialConnectAttempts));
      Serial.println ("Changing to Access Point mode..."); 
      createAPserver();    
      AP_MODE = true;
     }
    
}


/*----------------------------------------------------------
    Read meter parameters from EEPROM
  ----------------------------------------------------------*/
int readEEPROM(){
String myChannel;

  //  SSID
  Serial.println("Reading EEPROM ssid");

  ssid = "";
  for (int i = 0; i < 32; ++i)
  {
    ssid += char(EEPROM.read(i));
  }

  if (!(int)ssid.charAt(0)) return 0; // Parameters NOT found in EEPROM

  Serial.println();
  Serial.print("SSID: ");
  Serial.println(ssid); 
  
  //  password
  Serial.println("Reading EEPROM pass");

  password = "";
  for (int i = 32; i < 96; ++i)
  {
    password += char(EEPROM.read(i));
  }

  Serial.print("PASS: ");
  Serial.println(password);

  //  thingspeack - Channel ID
  Serial.println("Reading EEPROM Channel ID");

  myChannel = "";
  for (int i = 96; i < 104; ++i)
  {
    myChannel += char(EEPROM.read(i));
  }
  myChannelNumber = atol(myChannel.c_str());

  Serial.print("Channel ID: ");
  Serial.println(myChannel);

  //  thingspeack - Write API Key
  Serial.println("Reading EEPROM Write API Key");

  myWriteAPIKey = ""; 
  for (int i = 104; i < 136; ++i)
  {
    myWriteAPIKey += char(EEPROM.read(i));
  }

  Serial.print("Write APi Key: ");
  Serial.println(myWriteAPIKey);

  //  thingspeack - Read API Key
  Serial.println("Reading EEPROM Read API Key");

  myReadAPIKey = "";
  for (int i = 136; i < 168; ++i)
  {
    myReadAPIKey += char(EEPROM.read(i));
  }

  Serial.print("Read APi Key: ");
  Serial.println(myReadAPIKey);

  return 1; // Parameters found in EEPROM
}


/*----------------------------------------------------------
    Write meter parameters to EEPROM
  ----------------------------------------------------------*/
void writeEEPROM(String qsid, String qpass, String qchannel_id, String qwrite_api_key, String qread_api_key){
  //qsid = 32, qpass = 64, channel_id=8, write_api_key=32, read_api_key = 32

  for (int i = 0; i < 168; ++i) {
    EEPROM.write(i, 0);
  }
  Serial.println(qsid);
  Serial.println("");
  Serial.println(qpass);
  Serial.println("");
  Serial.println(qchannel_id);
  Serial.println("");
  Serial.println(qwrite_api_key);
  Serial.println("");
  Serial.println(qread_api_key);
  Serial.println("");

  Serial.println("writing eeprom ssid:");
  for (int i = 0; i < qsid.length(); ++i){
    EEPROM.write(i, qsid[i]);
    Serial.print("Wrote: ");
    Serial.println(qsid[i]);
  }
        
  Serial.println("writing eeprom pass:");
  for (int i = 0; i < qpass.length(); ++i){
    EEPROM.write(32 + i, qpass[i]);
    Serial.print("Wrote: ");
    Serial.println(qpass[i]);
  }
        
  Serial.println("writing eeprom Channel ID:");
  for (int i = 0; i < qchannel_id.length(); ++i){
    EEPROM.write(96 + i, qchannel_id[i]);
    Serial.print("Wrote: ");
    Serial.println(qchannel_id[i]);
  }

  Serial.println("writing eeprom Write API Key:");
  for (int i = 0; i < qwrite_api_key.length(); ++i){
    EEPROM.write(104 + i, qwrite_api_key[i]);
    Serial.print("Wrote: ");
    Serial.println(qwrite_api_key[i]);
  }

  Serial.println("writing eeprom Read API Key:");
  for (int i = 0; i < qread_api_key.length(); ++i){
    EEPROM.write(136 + i, qread_api_key[i]);
    Serial.print("Wrote: ");
    Serial.println(qread_api_key[i]);
  }
        
  EEPROM.commit();
}


/*----------------------------------------------------------
    Connect to AP and WiFi in WIFI_AP_STA and launch web 
  ----------------------------------------------------------*/
void createAPserver(){

  WiFi.mode(WIFI_STA);
  
  if(WiFi.status() != WL_CONNECTED){
    //AP Mode with no WiFi detected
    WiFi.disconnect();
    delay(100);

    Serial.println("");
    Serial.println("No WiFi Connection in AP MODE");
    Serial.println("Please verify your Network SSID name and password, and router connectivity");
  }
  else{
    Serial.println("");
    Serial.println("WiFi connected in AP MODE");
  }

  //access point 
  Serial.println("");
  Serial.println("Creating Accesspoint");
  WiFi.softAP(AP_ssid, "");
  Serial.print("Default IP address:\t");
  Serial.println(WiFi.softAPIP());

  //station part
  Serial.print("Connecting to...");
  Serial.println(ssid);
  Serial.print("with pass...");
  Serial.println(password);

  delay(10000);

  Serial.println("IP address: ");
  Serial.println(WiFi.localIP());
  Serial.println("WiFi Status: ");
  Serial.println(WiFi.status());

  generateBasicWebHtml();

  server.on("/", handleConnectionRoot);
  server.on("/instrucciones", handleConnectionInstructions);
  server.on("/configuracion", handleConnectionConfiguration);
  server.on("/enviar_configuracion", handleConnectionSendConfiguration);
  server.on("/enviar_wifi", handleConnectionSendWiFiConfiguration);
  server.on("/verificacion_wifi", handleConnectionVerificationWiFi);
  server.begin();

};


/*----------------------------------------------------------
    Create Basic HTML Content Pattern
  ----------------------------------------------------------*/
void generateBasicWebHtml(){
  
      //HTML CONTENT
      content_fixed_up = "<!DOCTYPE html>";
      content_fixed_up += "<html>";

      // HEAD
      content_fixed_up +="<head>";
      content_fixed_up +="<meta charset=\"UTF-8\">";
      content_fixed_up +="<meta name=\"viewport\" content=\"width=device-width, initial-scale=1.0\">";
      content_fixed_up ="<title>Medidor C02  Configuraci&oacute;n</title>";
      content_fixed_up += "</head>";

      // STYLES
      content_fixed_up ="<style>"; 
      content_fixed_up +="html, body { height: 100%; margin: 0; } ";
      content_fixed_up +="body { background-color: black; color: white; font-family: 'Courier New', Courier, monospace; } ";
      content_fixed_up +="button { border: 1px white solid; color: white; background-color: black; padding: 15px; margin: 5px; font-family: 'Arial'; text-decoration: none; font-size: 13px; width: 135px; cursor: pointer;} ";
      content_fixed_up +="a button  { text-decoration: none; color: white; cursor: pointer; }";
      content_fixed_up +="div#mensajes{ padding: 15px; width: 100%; margin: 20px auto; text-align: center; } ";
      content_fixed_up +="div#mensajes ol { text-align: left; } ";
      content_fixed_up +=".fail { color: red; }";
      content_fixed_up +="a.link { color: orange; text-decoration: none;}";
      content_fixed_up +=".success{ color: green; } ";
      content_fixed_up +=" .yellow { color: rgba(255, 255, 0, 0.678); } ";
      content_fixed_up +="h1.unicolor, footer p { color: #1F7E97; text-align: center; } ";
      content_fixed_up +=".content { margin: 0 auto; width: 85%; min-height: 100%; text-align: center; } ";
      content_fixed_up +="footer { border-top: 1px solid #1F7E97; height: 50px; margin-top: -50px; padding: 0 20px; } ";
      content_fixed_up +="main { padding: 20px; padding-bottom: 50px; } ";
      content_fixed_up +="@media (min-width:1024px){ .content { width: 60%; } div#mensajes { width: 50%; } } ";
      content_fixed_up += "</style>";

      //BODY
      content_fixed_up +="<body>";
      content_fixed_up +="<div class=\"content\">";
      content_fixed_up +="<main>";
      content_fixed_up +="<h1 class=\"unicolor\">Medidor de CO2 UNICEN</h1>";
      content_fixed_up +="<a href=\"/instrucciones\"><button>Instrucciones</button></a>";
      content_fixed_up +="<a href=\"/configuracion\"><button >Configuraci&oacute;n</button></a>";
      content_fixed_up+="<div id=\"mensajes\">";
      content_fixed_up +="<br>";

      content_fixed_down ="</div> ";
      content_fixed_down +="</main>";
      content_fixed_down +="</div>";
      content_fixed_down +="<footer>";
      content_fixed_down +="<p>2021 - Proyecto Abierto Medici&oacute;n CO2 -  <b>UNICEN</b></p>";
      content_fixed_down +="</footer>";
      content_fixed_down +="</body>";
      content_fixed_down +="</html>";
  
}


/*----------------------------------------------------------
    192.168.4.1/ content & functionality
  ----------------------------------------------------------*/
void handleConnectionRoot(){
  Serial.println("Root access in Html Web Page");
  if(WiFi.status() != WL_CONNECTED){
  
      content_dynamic = "<p class=\"fail\">Su dispositivo no posee conexi&oacute;n a una red WiFi</p>";
      content_dynamic += "<p>Por favor lea las Instrucciones y luego configure su conexi&oacute;n dentro de las secci&oacute;n Configuraci&oacute;n</p>";

    Serial.println("No WiFi");
  }
  else{
      content_dynamic = "<p class=\"success\">Su dispositivo est&aacute; conectado a la Red WiFi : ";
      content_dynamic += ssid + "</p>";
      content_dynamic += "<p>Si desea cambiar de red o ingresar nuevas credenciales de Thingspeak, por favor lea las Instrucciones y luego configure su conexi&oacute;n dentro de Configuraci&oacute;n</p>";
    
  };
  content = content_fixed_up + content_dynamic + content_fixed_down;
  server.send(200, "text/html", content);
}


/*----------------------------------------------------------
    192.168.4.1/instrucciones content & functionality
  ----------------------------------------------------------*/
void handleConnectionInstructions(){
  Serial.println("Button Event \"Instrucciones\" in HtmlWeb Page");
    
    content_dynamic = "<h2>Instrucciones</h2>";
    content_dynamic += "<p>Siguiendo los siguientes pasos usted puede configurar su dispositivo para que se conecte a una nueva red WiFi o tambi&eacute;n puede cambiar de red WiFi.</p>";
    content_dynamic += "<ol><li>Ingrese en Configuraci&oacute;n</li>";
    content_dynamic += "<li>Introducza el usuario y contrase&ntilde;a del dispositivo (si no lo posee consulte al administrador o a qui&eacute;n lo suministr&oacute;).</li>";
    content_dynamic += "<li>Si el acceso a su dispostivo fue exitoso, debe seleccionar la red de WiFi que desea conectar el dispositivo y su contrase&ntilde;a. En ese mismo paso puede agregar opcionalemente el canal y credenciales para la plataforma Thingspeak que registra en la nube las mediciones.</li>";
    
    content_dynamic += "<li>Si su red y contrase&ntilde;a de WiFi es correcta su dispositivo queda configurado y conectado a la red seleccionada, luego de 10 segundos se reiniciar&ntilde;. Caso contrario vuelva a intentarlo.</li></ol>";
    content_dynamic += "<p>Para saber m&aacute;s de Thingspeak y su uso puede visitar la informaci&oacute;n de nuestro proyecto <a class=\"link\" href=\"https://github.com/medicionco2/proyecto_medidor_co2/blob/main/src/mhz19/ESP32/IoT/README.md\" target=\"_blank\">aqu&iacute;<a>";
    content_dynamic += " o tambi&eacute;n accediendo a <a class=\"link\" href=\"https://thingspeak.com/\" target=\"_blank\">Thingspeak<a>. Recuerde que si usted est&aacute; viendo esta informaci&oacute;n es porque se ha conectado al dispositivo medidor, para visitar en la web dicha informaci&oacute;n deber&aacute; conectarse nuevamente a su red WiFi con su computadora o m&oacute;vil.</p>";
    content = content_fixed_up + content_dynamic + content_fixed_down;

    if(WiFi.status() != WL_CONNECTED){
      Serial.println("No WiFi");
    }
    else{
      Serial.println("WiFi Connected");
    }

    server.send(200, "text/html", content);
}
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
void loop() {

  int co2ppm = mhz19.getCO2();          // Request CO2 (as ppm)
  int temp = mhz19.getTemperature();    // Request Temperature (as Celsius)
  struct tm timeinfo;  
  char buffer [25];

  btnManager_prov (co2ppm);
  
  if (!AP_MODE){
    //Remote Controls
    remoteCalibration();
    remoteRestart();
    remoteTimeSet();

    // Measurements to computer for debugging purposes
    //
    //Serial.print("co2: ");
    Serial.print(co2ppm);
    //Serial.print("temp: ");
    Serial.print(",");
    Serial.println(temp);

    if (d%S==0){     // Telemetry is sent every S samplingPeriod seconds

   if (WiFi.status() != WL_CONNECTED)  connectWiFiModeSTA();
   
   if (WiFi.status() == WL_CONNECTED) {
      // Measurements to WiFi thingspeak IoT Platform 
      // 
      ThingSpeak.setField (1,co2ppm);
      ThingSpeak.setField (2,temp);
      ThingSpeak.setField (remote_calibrate_field,remote_calibrate_state); // remote calibrate field
      ThingSpeak.setField (remote_restart_field,remote_restart_state); // remote restart field
      ThingSpeak.setField (remote_timeset_field,remote_timeset_state); // remote timeset field

      int writeApiTS = ThingSpeak.writeFields(myChannelNumber, myWriteAPIKey.c_str());

      if(writeApiTS == 200){
        Serial.println("Data sent to Thingspeak.");
      }
      else{
        Serial.println("Thingspeak Communication Failure Number: " + String(writeApiTS));
        Serial.println("Thingspeak CH Num: " + String(myChannelNumber));
        Serial.println("Thingspeak Write API: " + String(myWriteAPIKey.c_str()));
        Serial.println("Thingspeak Read API: " + String(myReadAPIKey.c_str()));
      }
 
   } else {
      // Measurements must be sent later when WiFi is available
      if (saved2send < MAX_MM) saved2send++;
      mm2send[saved2send-1].s_co2ppm = co2ppm;
      mm2send[saved2send-1].s_temp   = temp;
      if(!getLocalTime(&timeinfo)){
        Serial.println("Failed to obtain time");
        return;
      }
      mm2send[saved2send-1].s_timeinfo = timeinfo;
      Serial.println("Measurement saved for later registration in the IoT platform...");
   }
     
  } else { // Saved telemetry, if any, is sent
    if (WiFi.status() == WL_CONNECTED && saved2send > 0) {
      ThingSpeak.setField (1,mm2send[saved2send-1].s_co2ppm);
      ThingSpeak.setField (2,mm2send[saved2send-1].s_temp);
      // Example: "2017-01-12 13:22:54-05"
      strftime (buffer,25,"%F %T-03",&(mm2send[saved2send-1].s_timeinfo)); // Example "2017-01-12 13:22:54-05"
      ThingSpeak.setCreatedAt(buffer);

      ThingSpeak.writeFields(myChannelNumber, myWriteAPIKey.c_str());
      Serial.print("Datos guardados anteriormente enviados a ThingSpeak: "); Serial.println(buffer);
      if (saved2send > 0) saved2send--;
     }
  }
    d++;

    CO2RGB_LED(co2ppm);

    delay(samplingPeriod);
  } 
  
  else { // Meter in Access Point mode
    Serial.println("AP mode"); // for debug
    server.handleClient();
  }


}

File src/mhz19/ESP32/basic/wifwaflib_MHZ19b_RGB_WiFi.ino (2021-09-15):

/*
  hello_MHZ19b_RGB_WiFi.ino - MH-Z19b CO2 sensor basic program for ESP32 
                              This program uses the library from
                                  https://github.com/WifWaf/MH-Z19
                              Warning level signal RGB LED
                              Push Button for configuation control
                                (1) If the button is held down for less than 
                                one second, it sets the CO2 baseline, 
                                (2) if the duration is longer than one second, 
                                the device goes to calibration mode.
                              Basic WiFi Server support

  Copyright (c) 2021 Elías Todorovich

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
You should have received a copy of the GNU General Public License
along with this program.  If not, see <https://www.gnu.org/licenses/>.
*/

#include "eco2.h"

/*----------------------------------------------------------
  Basic WiFi Server in a NodeMCU ESP32s SoC 
  ----------------------------------------------------------*/
#include <WiFi.h>
#include "secrets.h"

char ssid[]     = SECRET_SSID;   // your network SSID (name) 
char password[] = SECRET_PASS;   // your network password

WiFiServer server(80);

/*----------------------------------------------------------
    Connect your device to the wireless network
  ----------------------------------------------------------*/
void connectWiFi(){

    while (WiFi.status() != WL_CONNECTED){
        WiFi.begin(ssid, password);
        Serial.print(".");
        updateRGB_LED (true);         // Blink while connecting
        delay(3000);
    }

    // Display a notification that the connection is successful. 
    Serial.println("Connected"); 
}

/*----------------------------------------------------------
    MH-Z19 CO2 sensor setup
  ----------------------------------------------------------*/
void setup() {
  Serial.begin(9600);
  
#ifdef HWSERIAL
  Serial2.begin(BAUDRATE, SERIAL_8N1, rx2_pin, tx2_pin);
  mhz19.begin(Serial2);
#else
  mySerial.begin(BAUDRATE); 
  mhz19.begin(mySerial);
#endif
  
  mhz19.autoCalibration(false);     // make sure auto calibration is off

  RGB_LEDSetup();

  setRGB_LEDColor (0, 0, 255);  // Blue means warming or Configuring:
                                //   baseline setting or calibrating

  pinMode(button1.PIN, INPUT_PULLUP);
  attachInterrupt(button1.PIN, isr_button, CHANGE);

  updateRGB_LED (true);         // Blink while connecting
  connectWiFi();
  updateRGB_LED (false);

  Serial.println("");
  Serial.println("WiFi connected.");
  Serial.println("IP address: ");
  Serial.println(WiFi.localIP());
    
  server.begin();

  delay (180000); // Wait 3 minutes for warming purposes

  retrieveInfo_mhz19 ();
 
  Serial.println("co2[ppm],temp[°C]");
}

String prepareHtmlPage(int co2, int temp)
{
  String htmlPage;
  htmlPage.reserve(1024);               // prevent ram fragmentation
  htmlPage = F("HTTP/1.1 200 OK\r\n"
               "Content-Type: text/html\r\n"
               "Connection: close\r\n"  // the connection will be closed after completion of the response
               "Refresh: 6\r\n"         // refresh the page automatically every 6 sec
               "\r\n"
               "<!DOCTYPE HTML>"
               "<html> <body>"
               "<h1>Hello CO2</h1>"
               "<h2>CO2 baseline: ");
  htmlPage += CO2_base; // prints CO2 baseline
  htmlPage += F(" ppm </h2>");
               
  if (co2 > CO2_base+400) {
    // Red means high risk             
    htmlPage += F("<p style=\"color:red;\"> co2:  ");}
  else { htmlPage += F("<p> co2:  ");}
  htmlPage += co2; // prints CO2 measurement
  htmlPage += F(" ppm <br>"
                "temp:  ");
  htmlPage += temp; // temperature value
  htmlPage += F(" oC </p></body></html>"
                "\r\n");
  return htmlPage;
}

/*----------------------------------------------------------
    MH-Z19 CO2 sensor loop
  ----------------------------------------------------------*/
void loop() {
  int co2ppm = mhz19.getCO2();          // Request CO2 (as ppm)
  int temp = mhz19.getTemperature();    // Request Temperature (as Celsius)

  btnManager (co2ppm);

  // Measurements to computer for debugging purposes
  //
  //Serial.print("co2: "); 
  Serial.print(co2ppm);
  //Serial.print("temp: "); 
  Serial.print(","); 
  Serial.println(temp);

  // Measurements to WiFi Server 
  //
  WiFiClient client = server.available();
  // wait for a client (web browser) to connect
  if (client)
  {
//*    Serial.println("\n[Client connected]");
    while (client.connected())
    {
      // read line by line what the client (web browser) is requesting
      if (client.available())
      {
        String line = client.readStringUntil('\r');
//*        Serial.print(line);
        // wait for end of client's request, that is marked with an empty line
        if (line.length() == 1 && line[0] == '\n')
        {
          client.println(prepareHtmlPage(co2ppm, temp));
          break;
        }
      }
    }

    while (client.available()) {
      // but first, let client finish its request
      // that's diplomatic compliance to protocols
      // (and otherwise some clients may complain, like curl)
      // (that is an example, prefer using a proper webserver library)
      client.read();
    }

    // close the connection:
    client.stop();
//*    Serial.println("[Client disconnected]");
  }

  CO2RGB_LED(co2ppm);
  
  delay(samplingPeriod);
}

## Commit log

2021-06-19 Update README.md
    Instrucciones para programar el dispositivo
2021-06-19 Update README.md
    Materiales
2021-06-24 Tiempo de calentamiento del sensor corregido
2021-06-25 Update README.md
    Se explica el funcionamiento, para usuarios.
2021-06-25 Tiempos de calibración modificados según hoja de datos
2021-06-27 Add files via upload
    Nueva versión del manual del sensor mh-z19
2021-07-06 Update README.md
    Sobre el sensor
2021-07-06 Instrucciones para thingspeak
2021-07-06 Programa para thingspeak
2021-07-21 mejoras en ISR: mejores tiempos de ejecución y prevención de problemas de concurrencia
    [wifwaflib_MHZ19b_IoT_thingspeak.ino]
2021-08-09 Update wifwaflib_MHZ19b_BT_RGB.ino
    Cambios en input de boton por pulsaciones por ruido
2021-08-30 Delete src/mhz19/arduino_uno/BasicUsage directory
    Sin uso
2021-08-30 Actualización como embeber código de thingspeak
2021-09-04 inversion logica button
2021-09-04 Uso de librería thingspeak
2021-09-13 Antirrebote más ruido en el botón por SW
2021-09-28 Comunicación con ISR mediante variable volatile y sust. millis
2021-10-18 Se agrega funcionalidad en web de AP de ajuste de red seleccionando por numero
2021-10-19 Se agrega funcionalidad en web de ingreso de datos de Thingspeak, channel id, write api key, read api key. También se almacenan esos datos en la EEPROM
2021-10-20 Solucion de Bug que generaba errores en numeros de red (se mostraban numeros de un scan de red y el form web cotejaba con otro segundo scan)
2021-10-23 Funcionalidad de provisioning de parámetros del medidor agregada
2021-12-03 Archivo de Testeo de Nueva Interface Web y ajustes de parametros
2022-01-11 Integracion de nuevo provisioning, nuevas funcionalidad Web/Acces Point con funcionalidades existentes de medicion, thingspeak_provisionig_basic.ino + thingspeak_provisioning.ino
2022-01-12 Soporte para almacenar medidas cuando no hay WiFi
2022-01-19 Funcionalidad de persistencia de datos agregada
2022-02-28 Se agrega funcionalidad de calibracion remota, incuyendo contenido html, css, js, ino
2022-03-01 Se modulariza en una funcion la calibracion remota, remoteCalibration()
2022-03-02 Se agrega funcionalidad de reinicio remoto, modificando index.html, js.js, thingspeak_provisioning_remote_ctrl.ino
2022-03-03 Uso de writeField en funciones de calibracion y reinicio remoto, se agrega la funcion de ajuste de hora remota (debe agregarse la rutina de ajuste dentro), modificando index.html, js.js, thingspeak_p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
2022-03-18 Se agrega funcionalidad de aviso en thingspeak de calilbracion local
2022-05-27 Solucion bug AP cuando no hay WiFi, uso de acciones remotas cuando no es AP mode en loop, verificacion envio exitoso a TS en loop
    [thingspeak_provisioning_remote_ctrl.ino]
2022-07-28 Update README.md
    En mi repositorio se subirán las versiones de las cajas 3D a medida que se vaya desarrollando el proyecto.
2023-03-17 Agregados archivos stl
    [Caja.stl, Placa.stl, Tapa.stl]
2023-03-17 Agregado archivo nativo de Fusion360 (.f3z)
2023-03-17 agregue video de la caja
2023-07-06 Add files via upload
    Hoja de datos para la version c del sensor, actualmente la utilizada en el proyecto.

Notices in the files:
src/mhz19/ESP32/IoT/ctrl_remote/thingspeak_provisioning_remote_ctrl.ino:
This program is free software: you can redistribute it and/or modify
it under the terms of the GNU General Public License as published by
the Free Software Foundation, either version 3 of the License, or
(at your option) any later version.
